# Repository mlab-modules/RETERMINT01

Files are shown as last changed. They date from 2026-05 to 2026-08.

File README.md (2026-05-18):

# RETERMINT01 – RETERMINAL DM Interface Board

<div align="center">
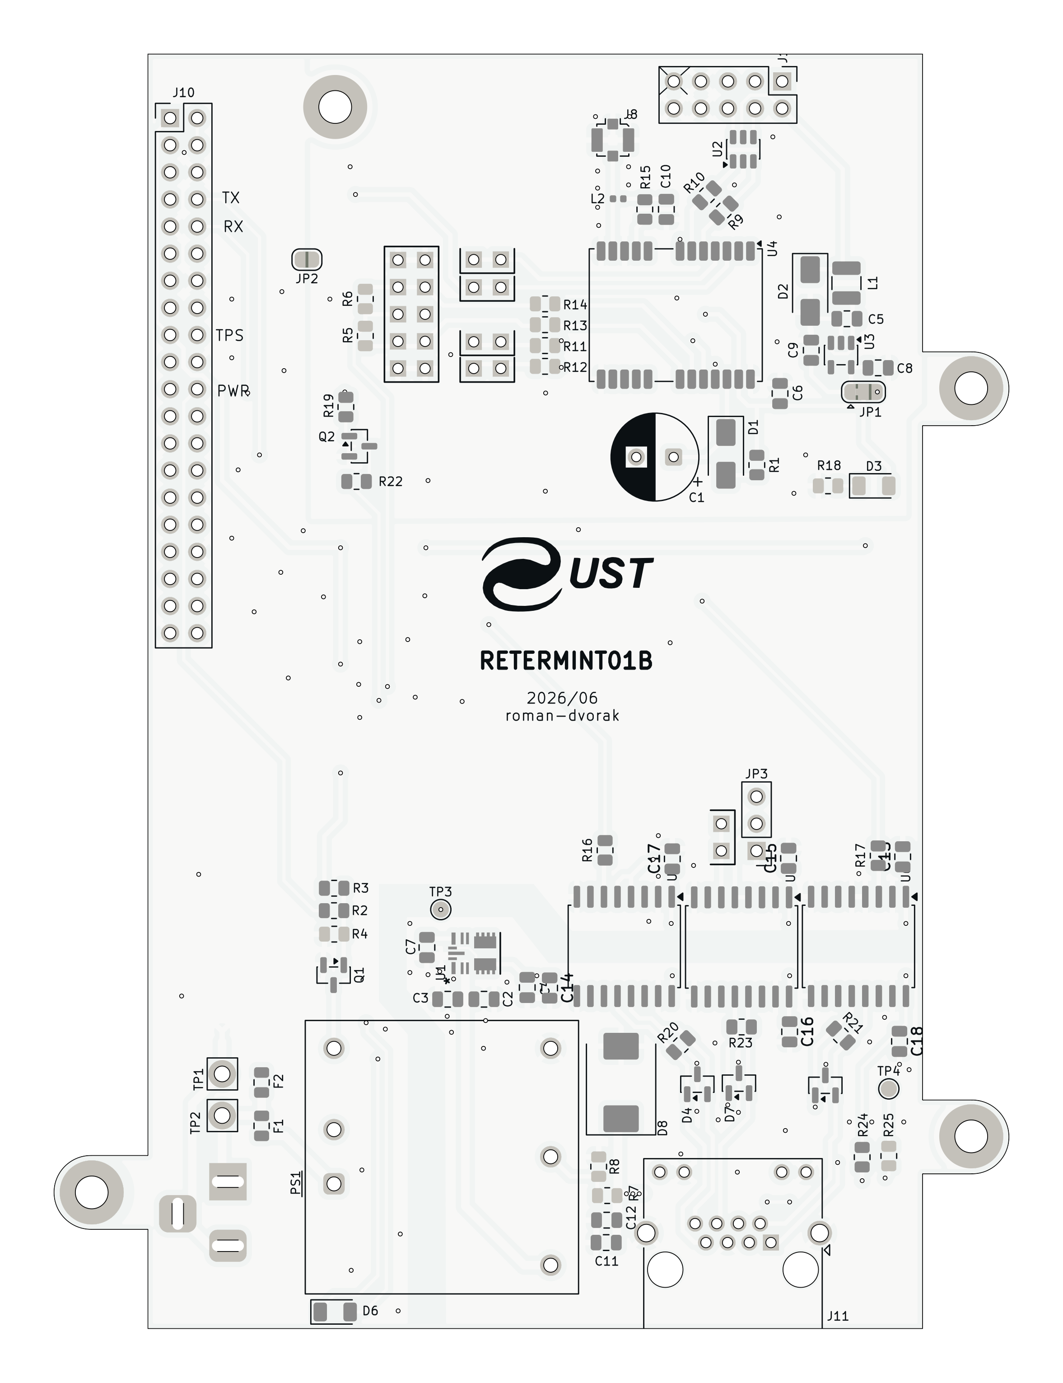
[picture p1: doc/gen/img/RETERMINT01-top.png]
Top side
  
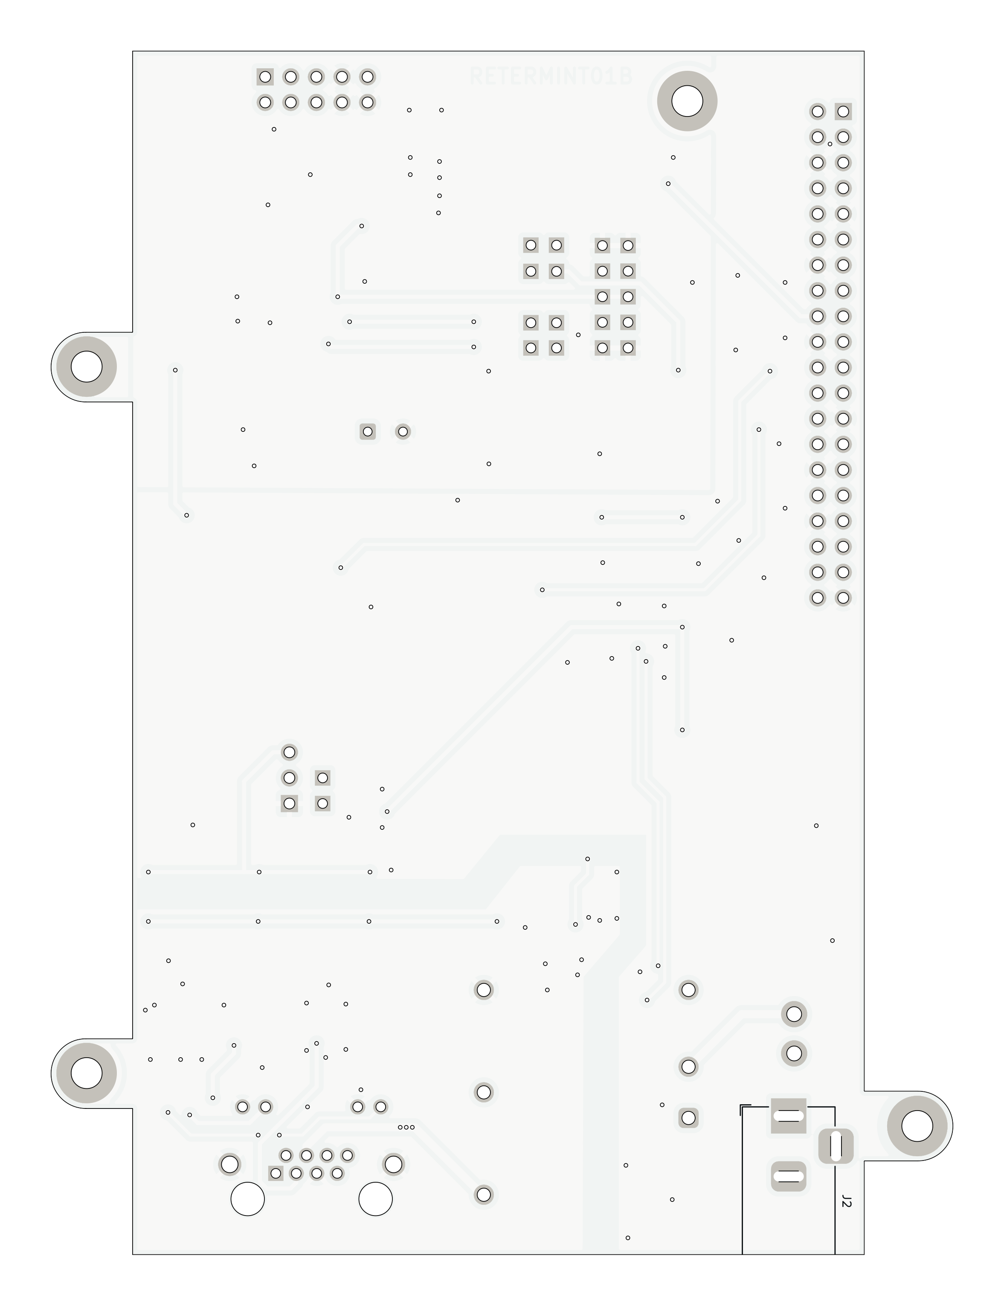
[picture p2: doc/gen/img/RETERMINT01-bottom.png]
Bottom side
  
</div>

RETERMINT01 is an interface board for the [reTerminal DM](https://wiki.seeedstudio.com/reterminal-dm/) by Seeed Studio. It adds a galvanically isolated industrial interface — **3× RS-485** bus, **isolated 24 V power supply** and the ability to **remotely switch off the power** of a connected field device via GPIO. All communication on the bus side is fully galvanically isolated from the reTerminal DM logic.

The board connects directly to the 40-pin GPIO header of the reTerminal DM.

## Features

- **3× RS-485** – galvanically isolated half-duplex channels (ADM2483xRW), up to 500 kbps
- **Isolated 24 V DC/DC** – 30 W Traco Power THN 30-2423WI, software-controllable (default OFF)
- **Remote power switching** – PS1 output controlled via `PWR_OFF` GPIO signal (active LOW)
- **5 V power module** – TI TPSM33606S5, powers the isolated RS-485 bus side
- **u-blox NEO-M9N GPS** – with u.FL antenna connector, USB configuration port and 1 F supercapacitor backup
- **Shielded RJ45 with LEDs** – for RS-485 field bus connection
- **ESD & overvoltage protection** – SM712 TVS on every RS-485 channel, USBLC6-2SC6 on GPS USB
- **2× 1 A fuse** – on 24 V input paths

## Schematic

Schematic

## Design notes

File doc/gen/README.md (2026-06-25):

# PCB

Board size: 89.6x119.5 mm (3.53x4.7 inches)

- This is the size of the rectangle that contains the board
- Thickness: 1.6 mm (63 mils)
- Material: FR4
- Finish: HAL
- Layers: 2
- Copper thickness: 35 µm

Solder mask: TOP / BOTTOM

- Color: Green

Silk screen: TOP / BOTTOM

- Color: White

# Important sizes

Clearance: 0.2 mm (8 mils)

Track width: 0.2 mm (8 mils)

- By design rules: 0.0 mm (0 mils)

Drill: 0.4 mm (16 mils)

- Vias: 0.4 mm (16 mils) [Design: 0.4 mm (16 mils)]
- Pads: 0.9 mm (35 mils)
- The above values are real drill sizes, they add 0.1 mm (4 mils) to plated holes (PTH)

Via: 0.6/0.3 mm (24/12 mils)

- By design rules: 0.5/0.3 mm (20/12 mils)
- Micro via: yes [0.2/0.1 mm (8/4 mils)]
- Buried/blind via: yes
- Total: 124 (thru: 124 buried/blind: 0 micro: 0)

Outer Annular Ring: 0.1 mm (4 mils)

- By design rules: 0.2 mm (8 mils)

Eurocircuits class: 6C
- Using min drill 0.35 mm for an OAR of 0.13 mm

# General stats

Components count: (SMD/THT)

- Top: 64/23 (SMD + THT)
- Bottom: 0/2 (THT)

Defined tracks:

- 0.2 mm (8 mils)
- 0.3 mm (12 mils)
- 0.4 mm (16 mils)
- 0.8 mm (31 mils)
- 1.0 mm (39 mils)

Used tracks:

- 0.2 mm (8 mils) (6) defined: yes
- 0.3 mm (12 mils) (113) defined: yes
- 0.4 mm (16 mils) (247) defined: yes
- 0.7 mm (28 mils) (1) defined: no
- 0.8 mm (31 mils) (37) defined: yes

Defined vias:

Used vias:

- 0.6/0.3 mm (24/12 mils) (Count: 124, Aspect: 2.7 A) defined: no

Holes (excluding vias):

- 0.8 mm (31 mils) (2)
- 0.89 mm (35 mils) (20)
- 0.89 mm (35 mils) (12)
- 1.0 mm (39 mils) (53)
- 1.24 mm (49 mils) (6)
- 1.4 mm (55 mils) (2)
- 1.57 mm (62 mils) (2)
- 3.0 mm (118 mils) (4)
- 3.25 mm (128 mils) (2)

Oval holes:

- 1.0x3.0 mm (39x118 mils) (3)

Drill tools (including vias and computing adjusts and rounding):

- 0.4 mm (16 mils) (124)
- 0.9 mm (35 mils) (2)
- 1.0 mm (39 mils) (32)
- 1.1 mm (43 mils) (56)
- 1.35 mm (53 mils) (6)
- 1.5 mm (59 mils) (2)
- 1.65 mm (65 mils) (2)
- 3.1 mm (122 mils) (4)
- 3.25 mm (128 mils) (2)

Solder paste stats:

Using a paste with 87.75 % alloy, that has an specific gravity for the alloy of 7.4 g/cm³
and 1.0 g/cm³ for the flux. This paste has an specific gravity of  4.15 g/cm³.

The stencil thickness is  0.12 mm.

| Side | Pads with paste | Area [mm²] | Paste [g] |
|---|---|---|---|
| Total  | 215 | 299.03 | 1.49 |

Note: this is just an approximation to the theoretical value. Margins of the solder mask and waste aren't computed.

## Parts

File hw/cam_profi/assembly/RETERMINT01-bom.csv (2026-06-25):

Component | Description | Part | References | Value | Footprint | Quantity Per PCB | Datasheet | ust_id | height | mouser part number | mouser price/stock | manufacturer_name | manufacturer_part_number
1 |  | C-Device | C10 | 47pF | C_0805_2012Metric | 1 |  | 5c70984712875079b91f8b38
2 | Unpolarized capacitor, small symbol | C_Small | C3C12C13C14C15C16C17C18 | 100nF | C_0805_2012Metric | 8 |  | 5c70984712875079b91f8b4c
3 |  | C-Device | C9 | 100nF | C_0805_2012Metric | 1 |  | 5c70984712875079b91f8b4c
4 | Unpolarized capacitor, small symbol | C_Small | C2C4C11 | 1uF | C_0805_2012Metric | 3 |  | 5c70984712875079b91f8b50
5 |  | C-Device | C6C7C8 | 1uF | C_0805_2012Metric | 3 |  | 5c70984712875079b91f8b50
6 |  | C-Device | C5 | 10uF | C_0805_2012Metric | 1 |  | 5c70984812875079b91f8bbe
7 |  | CP-Device | C1 | 1F | CP_Radial_D8.0mm_P3.50mm | 1 |  | 5c70984412875079b91f8873
8 |  | LED-Device | D6 | GREEN | LED_1206_3216Metric | 1 |  | 5c70984412875079b91f8895
9 |  | D-Device | D1D2 | M4 | D_SMA | 2 |  | 5c70984512875079b91f88ac
10 | 7V/12V, 600W Asymmetrical TVS Diode Array, SOT-23 | SM712_SOT23 | D4D5D7 | SM712_SOT23 | SOT-23 | 3 | https://www.littelfuse.com/~/media/electronics/datasheets/tvs_diode_arrays/littelfuse_tvs_diode_array_sm712_datasheet.pdf.pdf | ?
11 | Schottky diode, small symbol | D_Schottky_Small | D8 | SMCJ33A | D_SMC | 1
12 | Fuse, small symbol | Fuse_Small | F1F2 | 1A | Fuse_0805_2012Metric | 2
13 | Generic connector, double row, 02x05, odd/even pin numbering scheme (row 1 odd numbers, row 2 even numbers), script generated (kicad-library-utils/schlib/autogen/connector/) | Conn_02x05_Odd_Even | J1 | Conn_02x05_Odd_Even | PinHeader_2x05_P2.54mm_Vertical | 1
14 | 2x01 2.54 mm pitch header, 2 pins next to each other are connected | HEADER_2x01_PARALLEL | J9 | HEADER_2x01_PARALLEL | Straight_2x01 | 1
15 | RJ connector, 8P8C (8 positions 8 connected), two LEDs, Shielded | RJ45_LED_Shielded | J11 | RJ45_LED_Shielded | RJ45_Amphenol_RJHSE538X | 1
16 | Raspberry Pi 4 Model B | Raspberry_Pi_4 | J10 | Raspberry_Pi_4 | PinHeader_2x20_P2.54mm_Vertical | 1 | https://datasheets.raspberrypi.com/rpi4/raspberry-pi-4-datasheet.pdf
17 | small coaxial connector (BNC, SMA, SMB, SMC, Cinch/RCA, LEMO, ...) | Conn_Coaxial_Small | J8 | u.fl | U.FL_Molex_MCRF_73412-0110_Vertical | 1 |  | 5ed7ac8e12875004e15a62c8
18 |  | L-Device | L2 | 27nH | L_0402_1005Metric | 1 | LQG15HS27NJ02D | 618cbf071287506e2801ed7e
19 |  | L-Device | L1 | NL322522T-101K | L_1210_3225Metric | 1 |  | 5c70984412875079b91f87fb
20 | 30 Watt DC/DC converter, industrial, 4:1 input, encpasulated, 1.0" x 1.0" metal package | THN_30-2423WI | PS1 | THN-30-2415WIR | Converter_DCDC_TRACO_THN30-xxxx_THT | 1 | https://tracopower.com/thn30wi-datasheet/ |  | 10.4 | 495-THN30-2415WIR | https://www.mouser.co.uk/ProductDetail/TRACO-Power/THN-30-2423WI?qs=ckJk83FOD0VxUQUqsS4xBQ%3D%3D | Traco Power | THN-30-2415WIR
21 | NPN transistor, base/emitter/collector | Q_NPN_BEC | Q1Q2 | BC817-25 | SOT-23 | 2 |  | 5c70984712875079b91f8aea
22 |  | R-Device | R15 | 10R | R_0805_2012Metric | 1 |  | 5c70984512875079b91f896d
23 |  | R-Device | R1 | 22R | R_0805_2012Metric | 1 |  | 5c70984512875079b91f896f
24 |  | R-Device | R9R10R16R17 | 33R | R_0805_2012Metric | 4 |  | 5c70984512875079b91f8970
25 | Resistor | R | R19R20R21R22R23R24 | 220R | R_0805_2012Metric | 6 |  | 5c70984512875079b91f897f
26 | Resistor | R | R2 | 1k | R_0805_2012Metric | 1 |  | 5c70984512875079b91f898c
27 |  | R-Device | R3 | 10k | R_0805_2012Metric | 1 |  | 5c70984612875079b91f899f
28 | Isolated RS485/RS422 Transceiver, Half-Duplex, 500kbps, SOIC-16W | ADM2483xRW | U5U6U7 | ADM2483xRW | SOIC-16W_7.5x10.3mm_P1.27mm | 3 | https://www.analog.com/media/en/technical-documentation/data-sheets/adm2483.pdf
29 |  | MIC5504-3.3YM5-Regulator_Linear | U3 | MIC5504-3.3YM5 | SOT-23-5 | 1 | http://ww1.microchip.com/downloads/en/DeviceDoc/MIC550X.pdf | 5c7255e81287500b4e112ea2
30 |  | NEO-M8P-RF_GPS | U4 | NEO-M9N | ublox_NEO | 1 | https://www.u-blox.com/sites/default/files/NEO-M8P_DataSheet_%28UBX-15016656%29.pdf | 5fa0faaf12875025b3977985
31 |  | TPSM33606S5QRDNRQ1 | U1 | TPSM33606S5QRDNRQ1 | RDN0011A_TEX | 1 | https://www.ti.com/lit/gpn/tpsm33606-q1
32 |  | USBLC6-2SC6-Power_Protection | U2 | USBLC6-2SC6 | SOT-23-6 | 1 | http://www2.st.com/resource/en/datasheet/CD00050750.pdf | 5e82e0691287502a334a778c

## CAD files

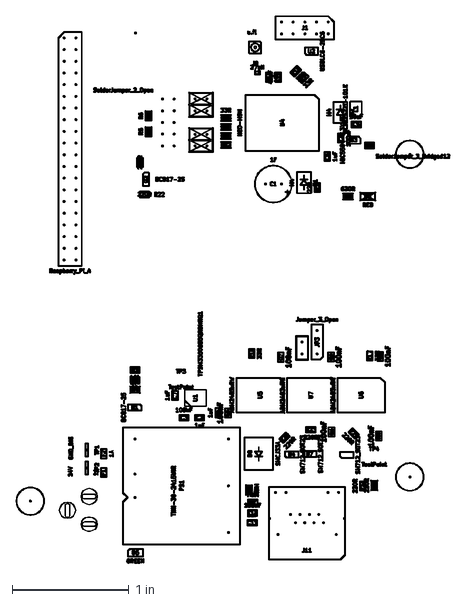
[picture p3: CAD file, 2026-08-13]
doc/gen/dxf/RETERMINT01-F_Fab.dxf
3.71 x 4.68 in

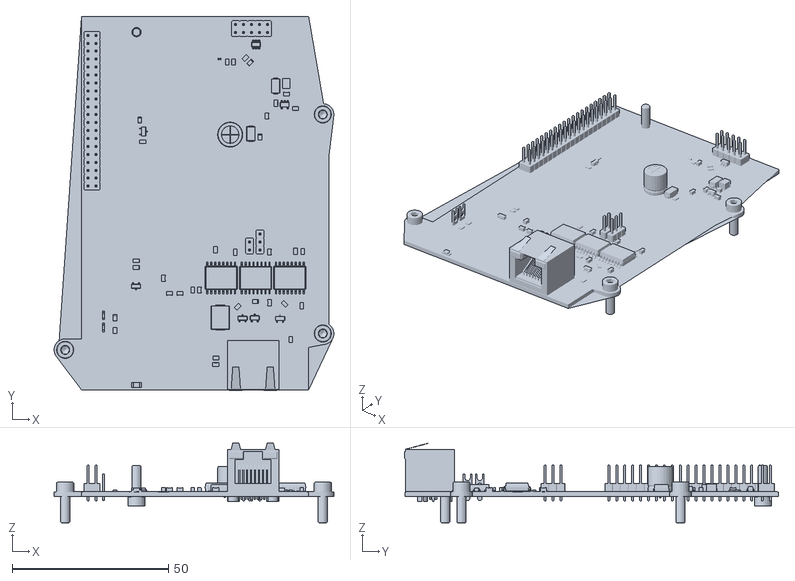
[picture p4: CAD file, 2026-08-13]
doc/gen/mesh/RETERMINT01.stl
89.6 x 119.7 x 25.5

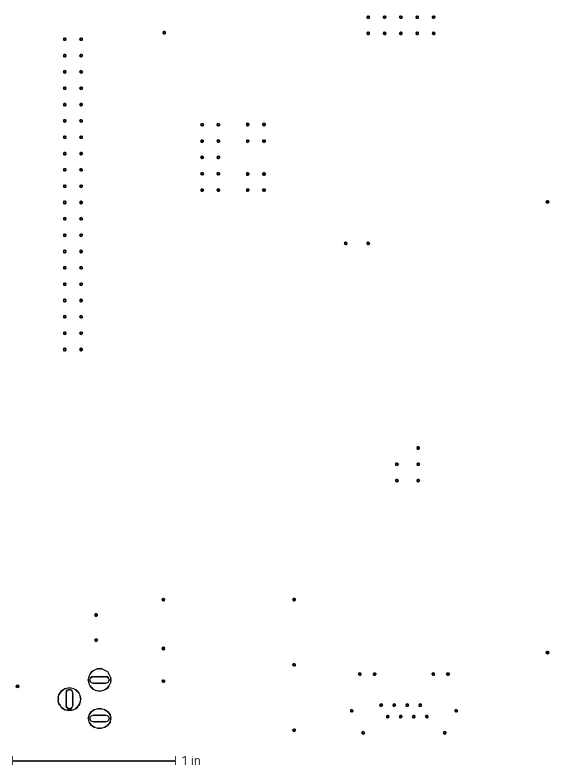
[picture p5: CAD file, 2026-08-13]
doc/gen/dxf/RETERMINT01-User_3.dxf
3.26 x 4.40 in

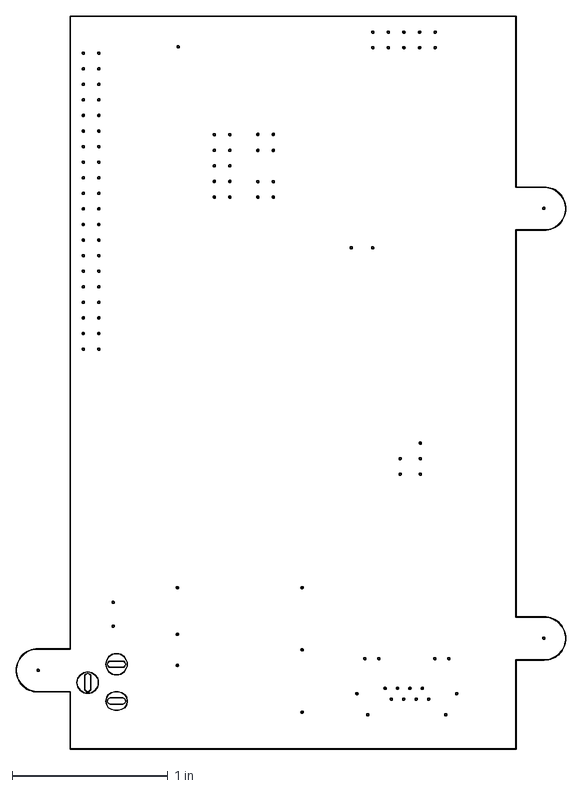
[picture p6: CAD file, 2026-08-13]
doc/gen/dxf/RETERMINT01-Edge_Cuts.dxf
3.53 x 4.71 in

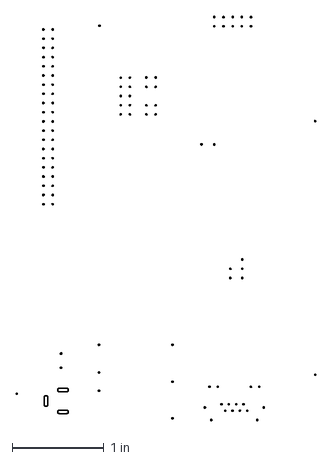
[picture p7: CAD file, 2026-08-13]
doc/gen/dxf/RETERMINT01-F_Adhesive.dxf
3.26 x 4.40 in

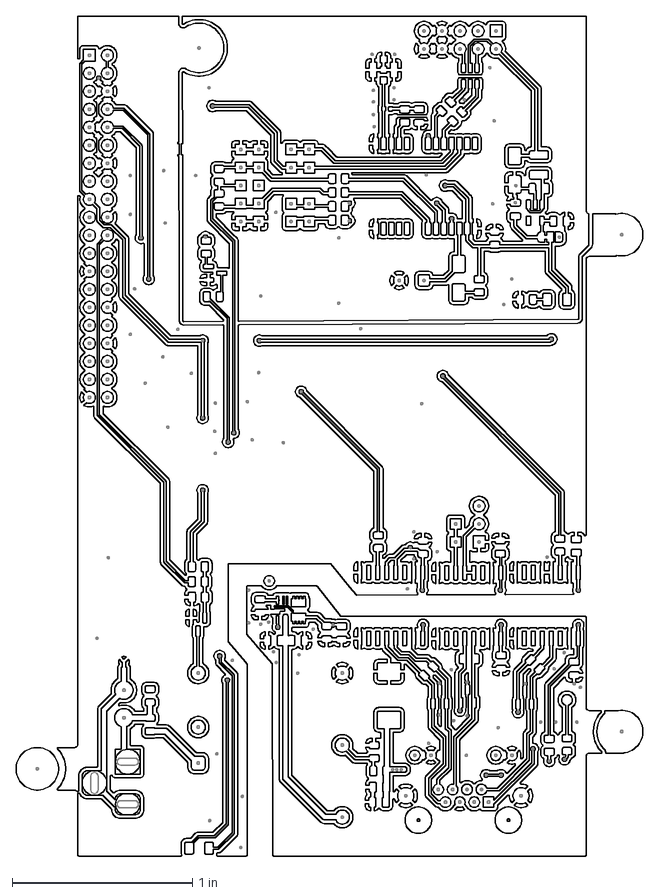
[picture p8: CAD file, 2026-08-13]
doc/gen/dxf/RETERMINT01-F_Cu.dxf
3.48 x 4.67 in

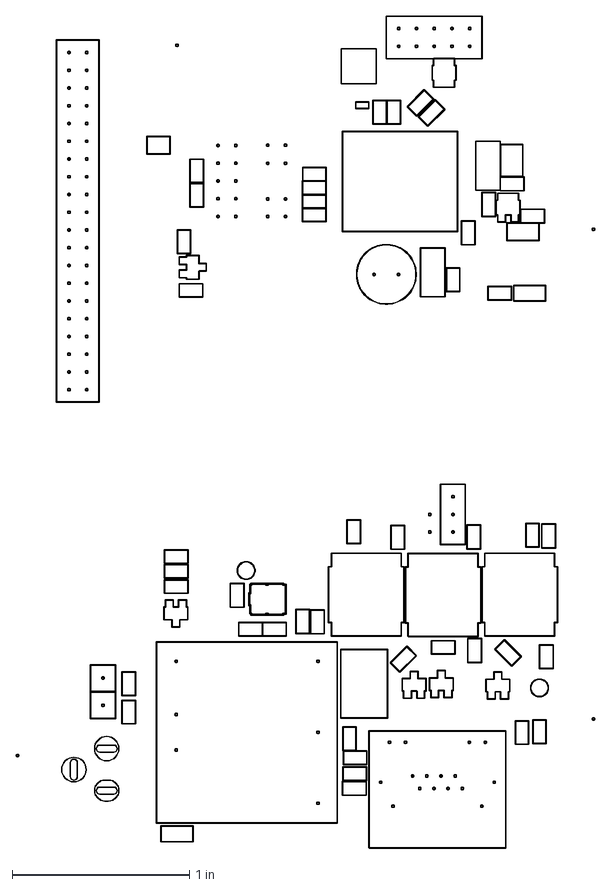
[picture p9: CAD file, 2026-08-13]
doc/gen/dxf/RETERMINT01-F_Courtyard.dxf
3.26 x 4.69 in

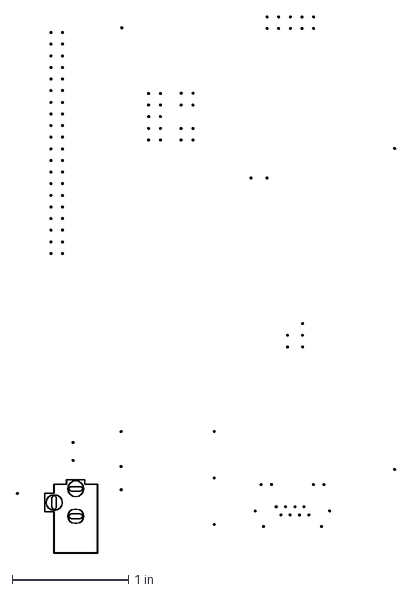
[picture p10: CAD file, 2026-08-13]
doc/gen/dxf/RETERMINT01-B_Courtyard.dxf
3.26 x 4.62 in

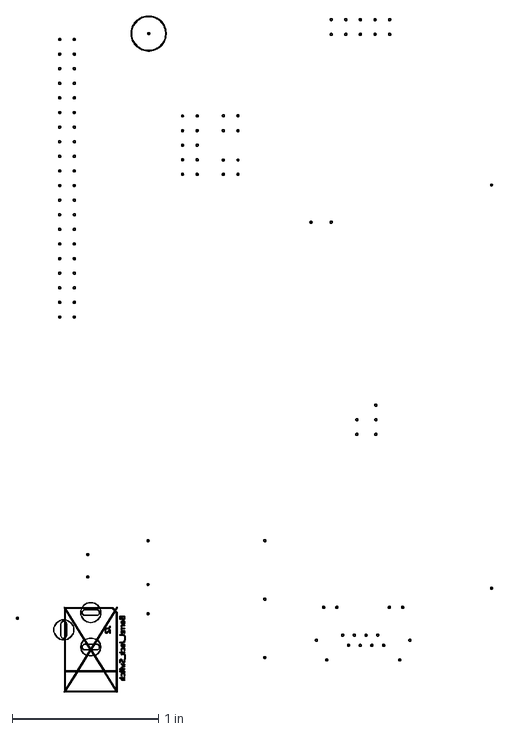
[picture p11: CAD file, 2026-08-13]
doc/gen/dxf/RETERMINT01-B_Fab.dxf
3.26 x 4.63 in

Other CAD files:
doc/gen/dxf/RETERMINT01-B_Cu.dxf
doc/gen/dxf/RETERMINT01-B_Mask.dxf
doc/gen/dxf/RETERMINT01-B_Silkscreen.dxf
doc/gen/dxf/RETERMINT01-F_Mask.dxf
doc/gen/dxf/RETERMINT01-F_Paste.dxf
doc/gen/dxf/RETERMINT01-F_Silkscreen.dxf

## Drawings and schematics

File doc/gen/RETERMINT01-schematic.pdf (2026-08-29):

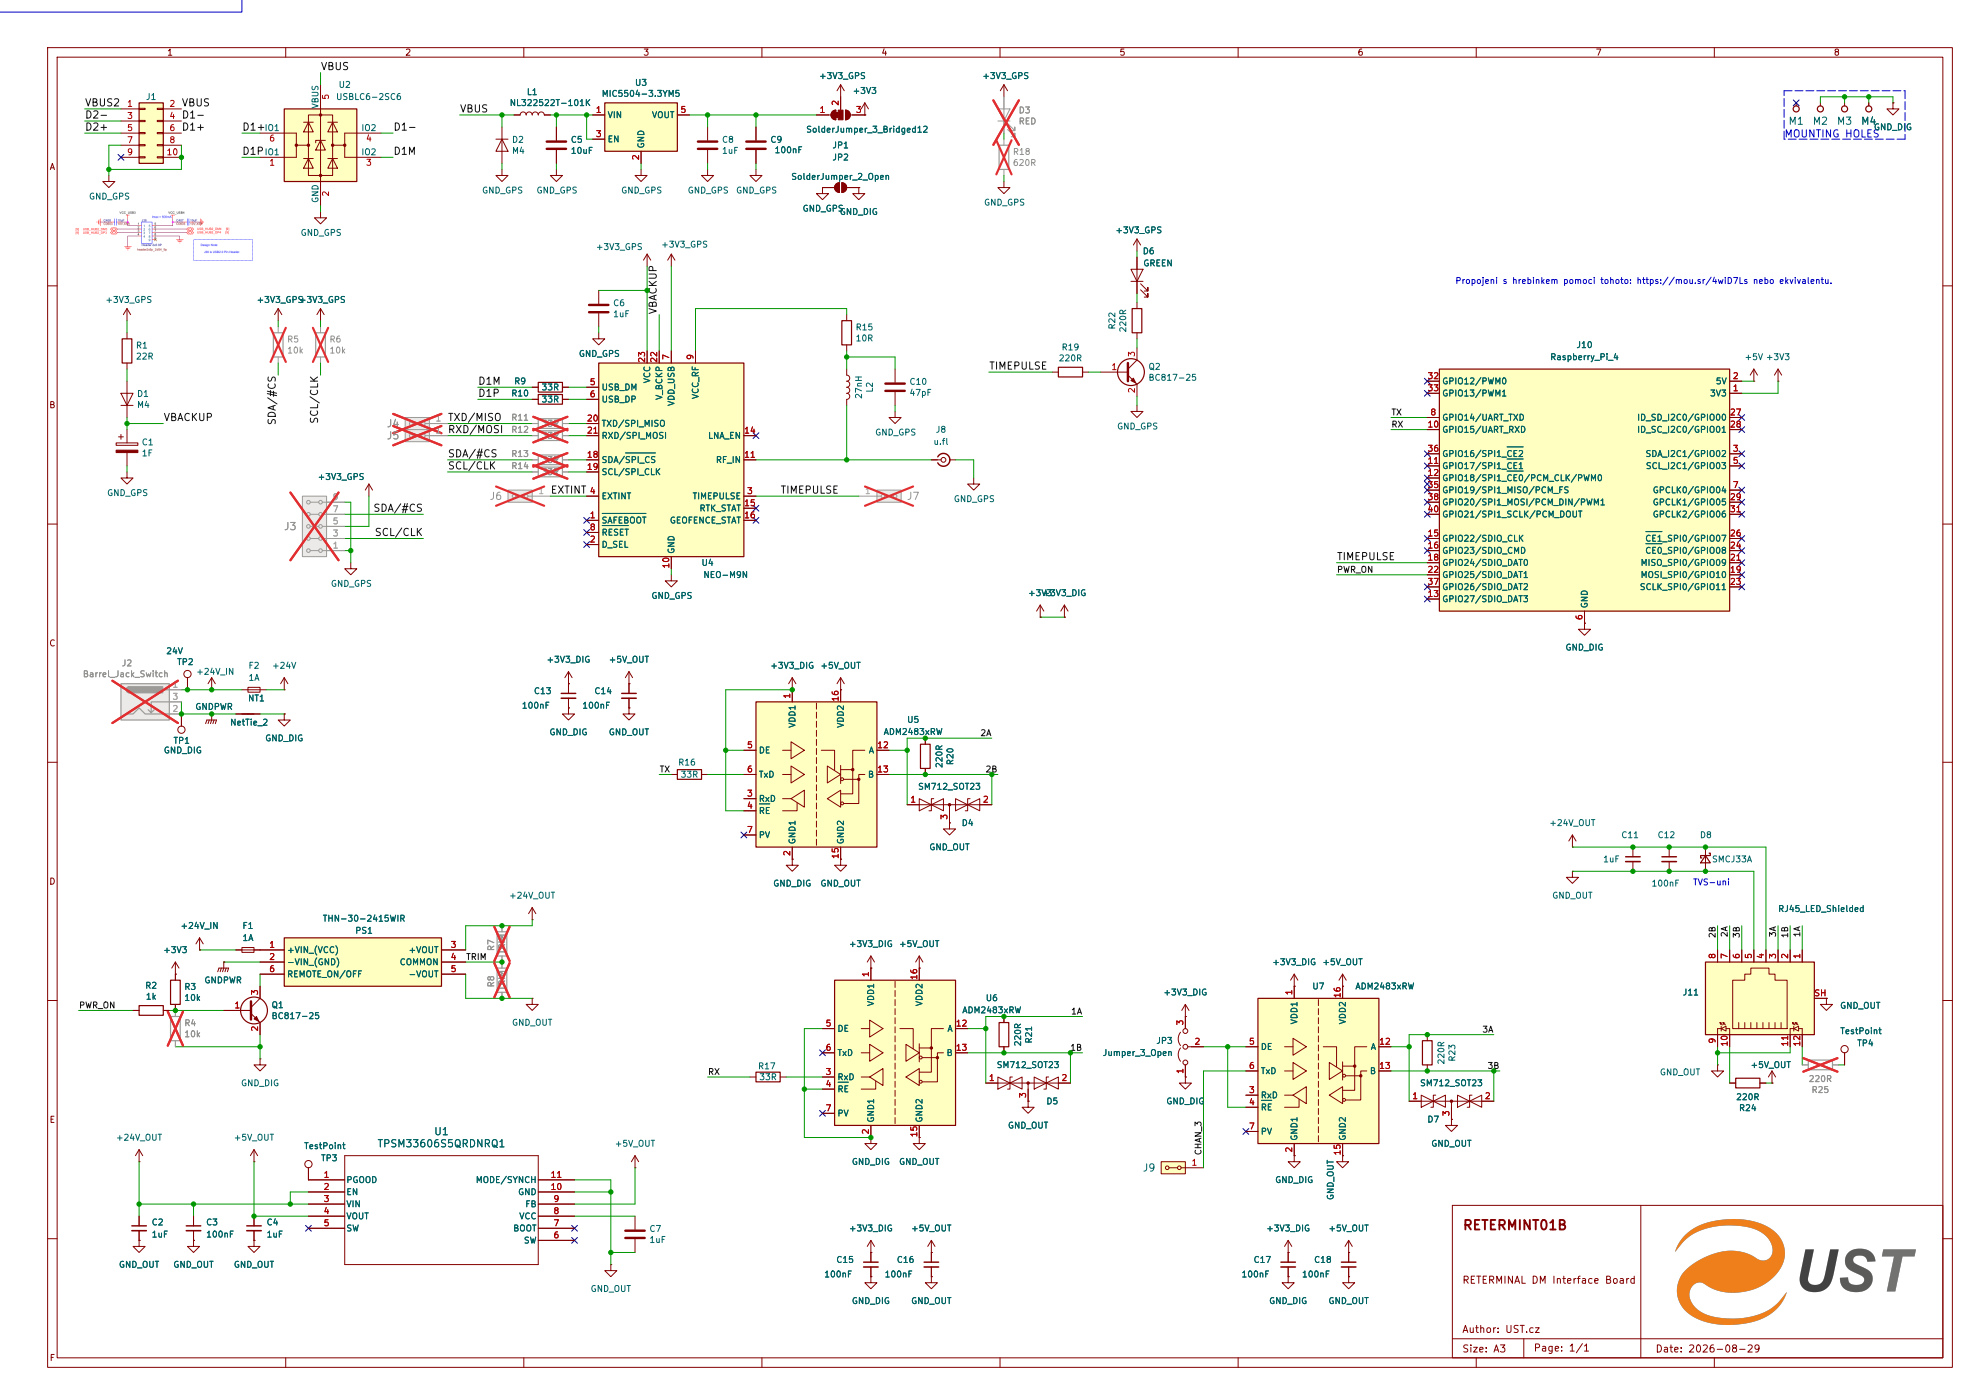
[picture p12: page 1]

Propojeni s hrebinkem pomoci tohoto: https://mou.sr/4wiD7Ls nebo ekvivalentu.

RETERMINAL DM Interface Board +5V_OUT

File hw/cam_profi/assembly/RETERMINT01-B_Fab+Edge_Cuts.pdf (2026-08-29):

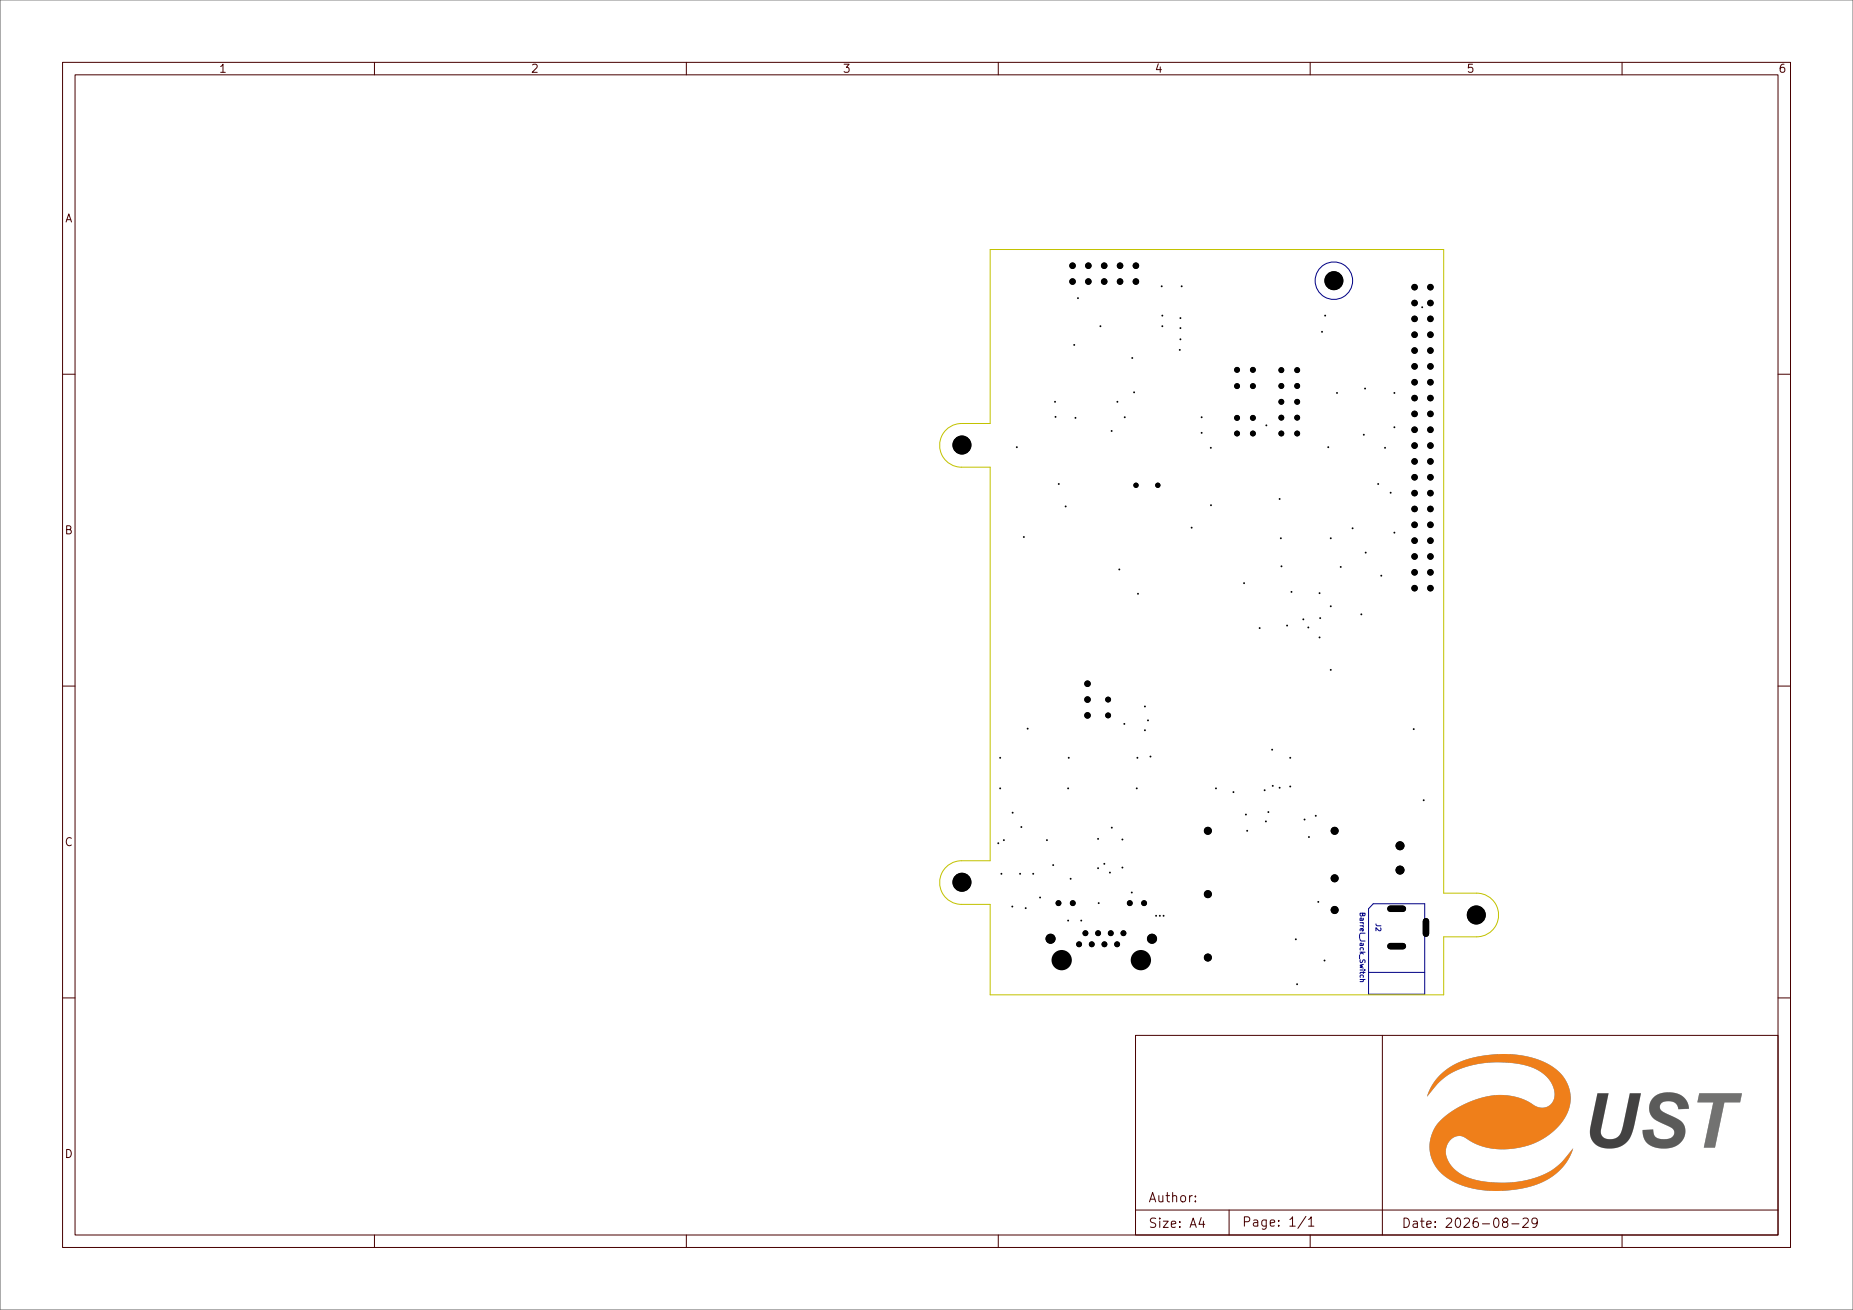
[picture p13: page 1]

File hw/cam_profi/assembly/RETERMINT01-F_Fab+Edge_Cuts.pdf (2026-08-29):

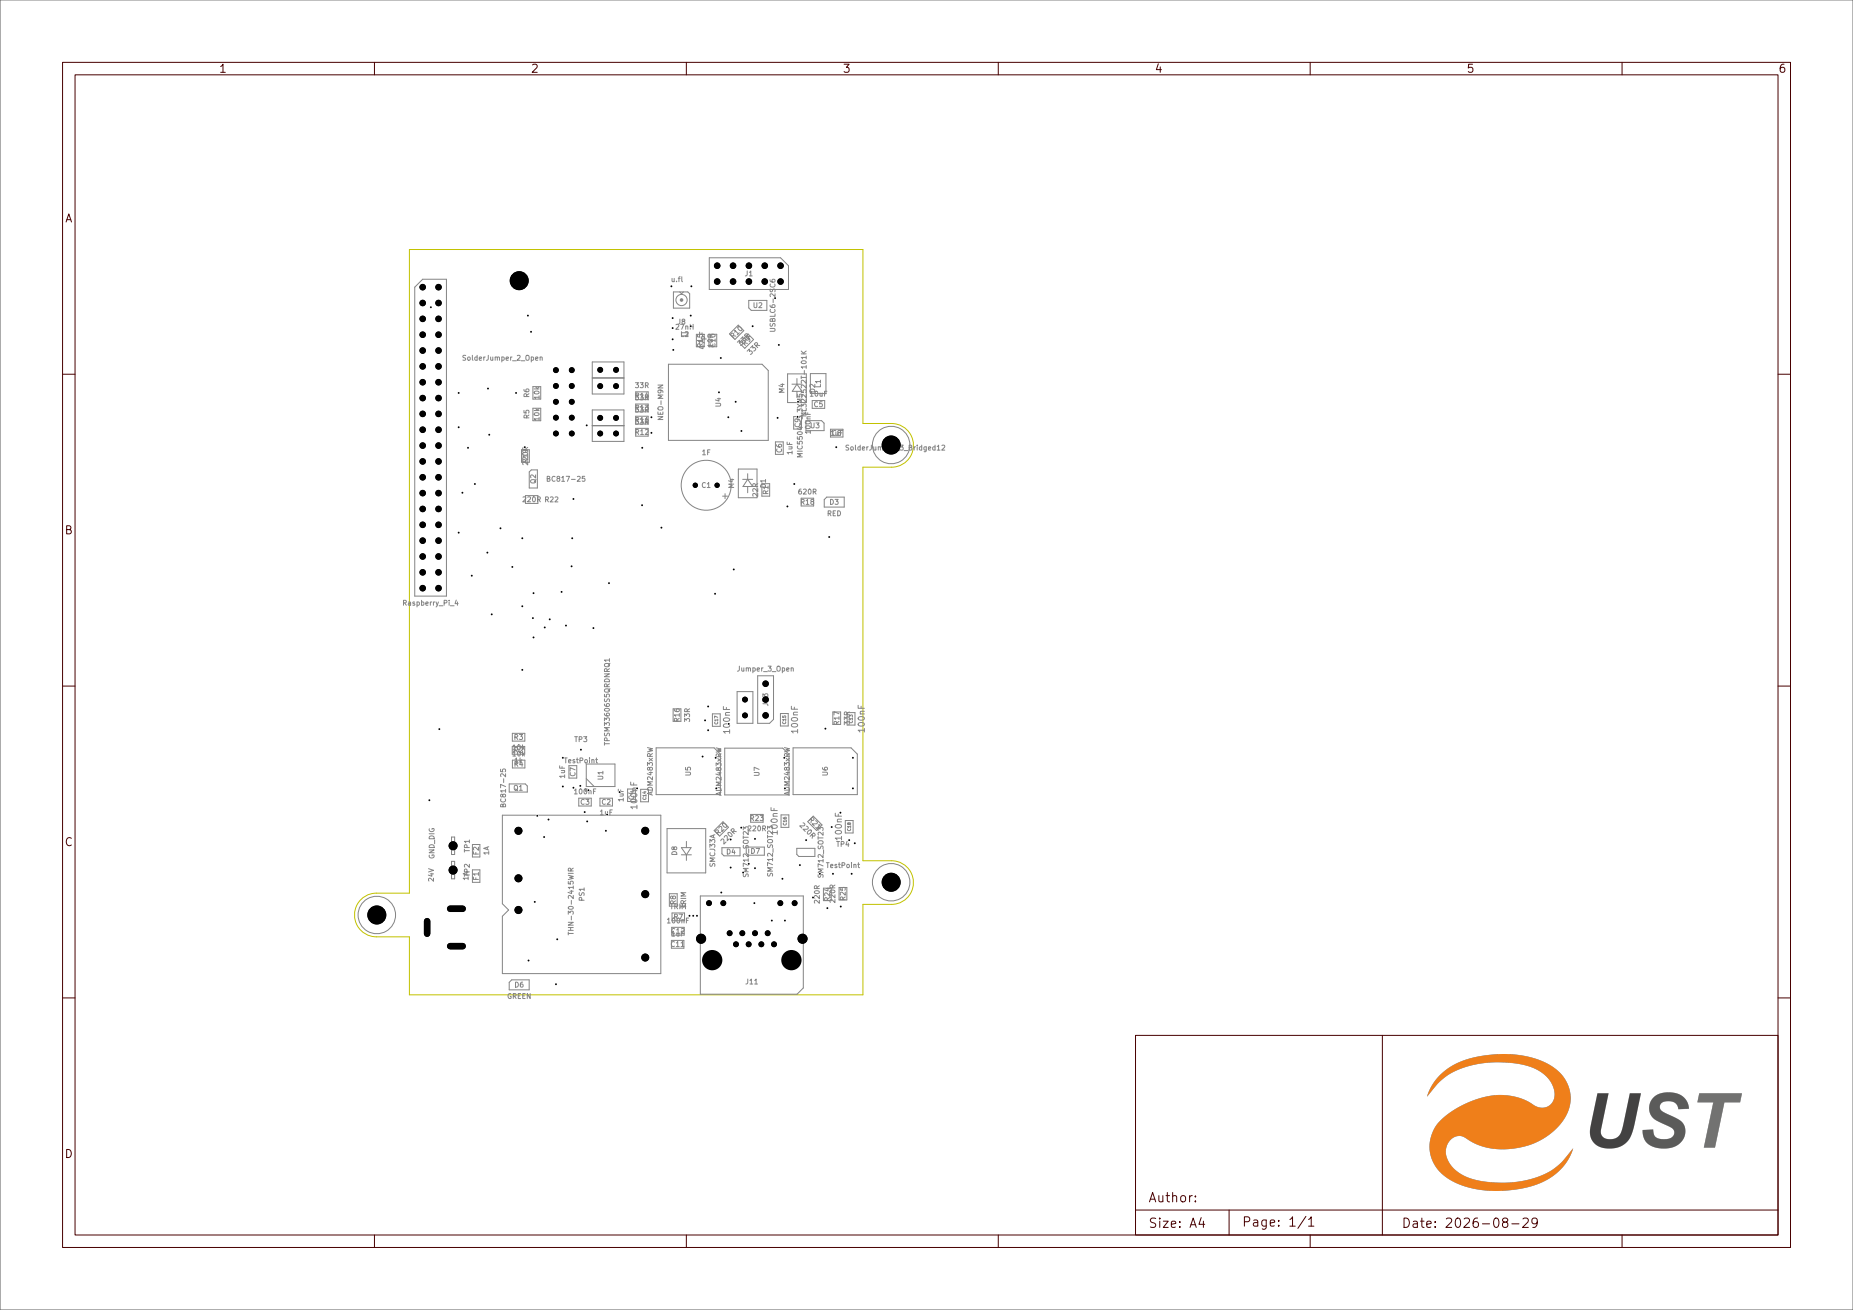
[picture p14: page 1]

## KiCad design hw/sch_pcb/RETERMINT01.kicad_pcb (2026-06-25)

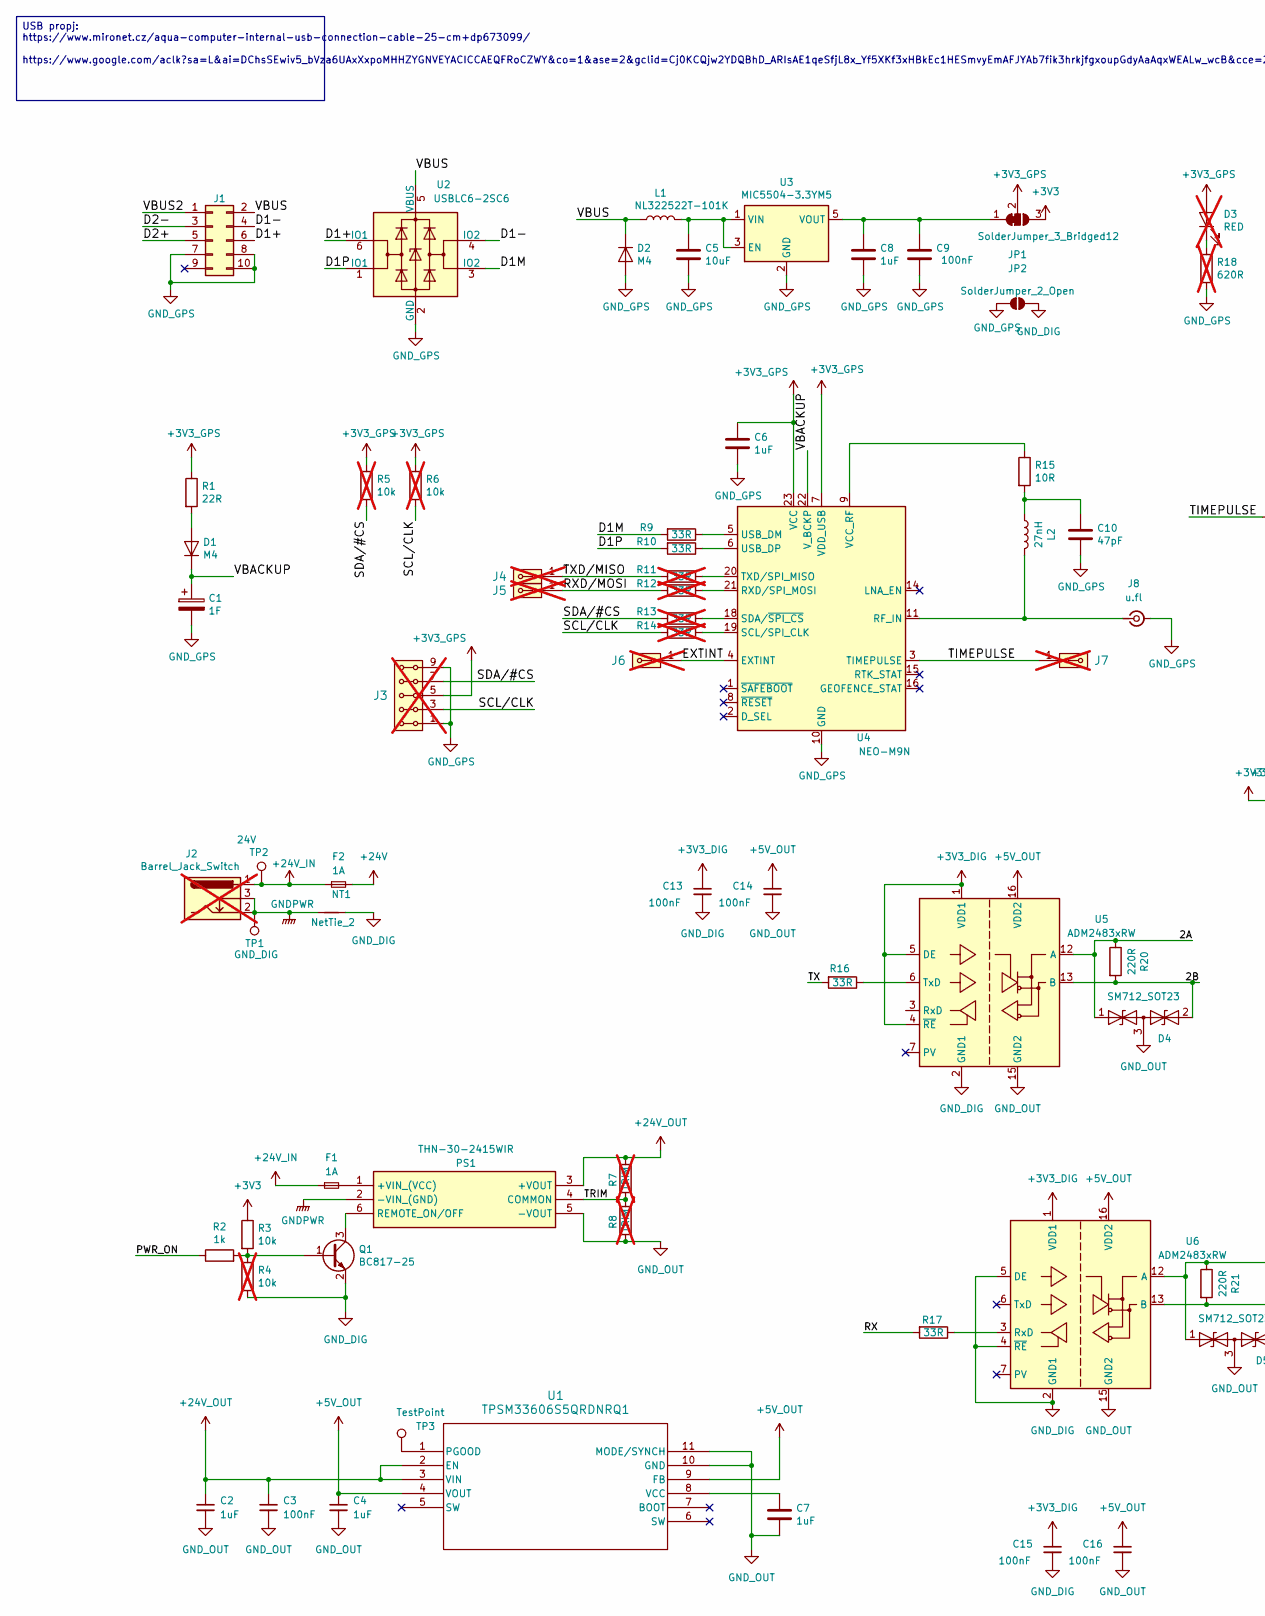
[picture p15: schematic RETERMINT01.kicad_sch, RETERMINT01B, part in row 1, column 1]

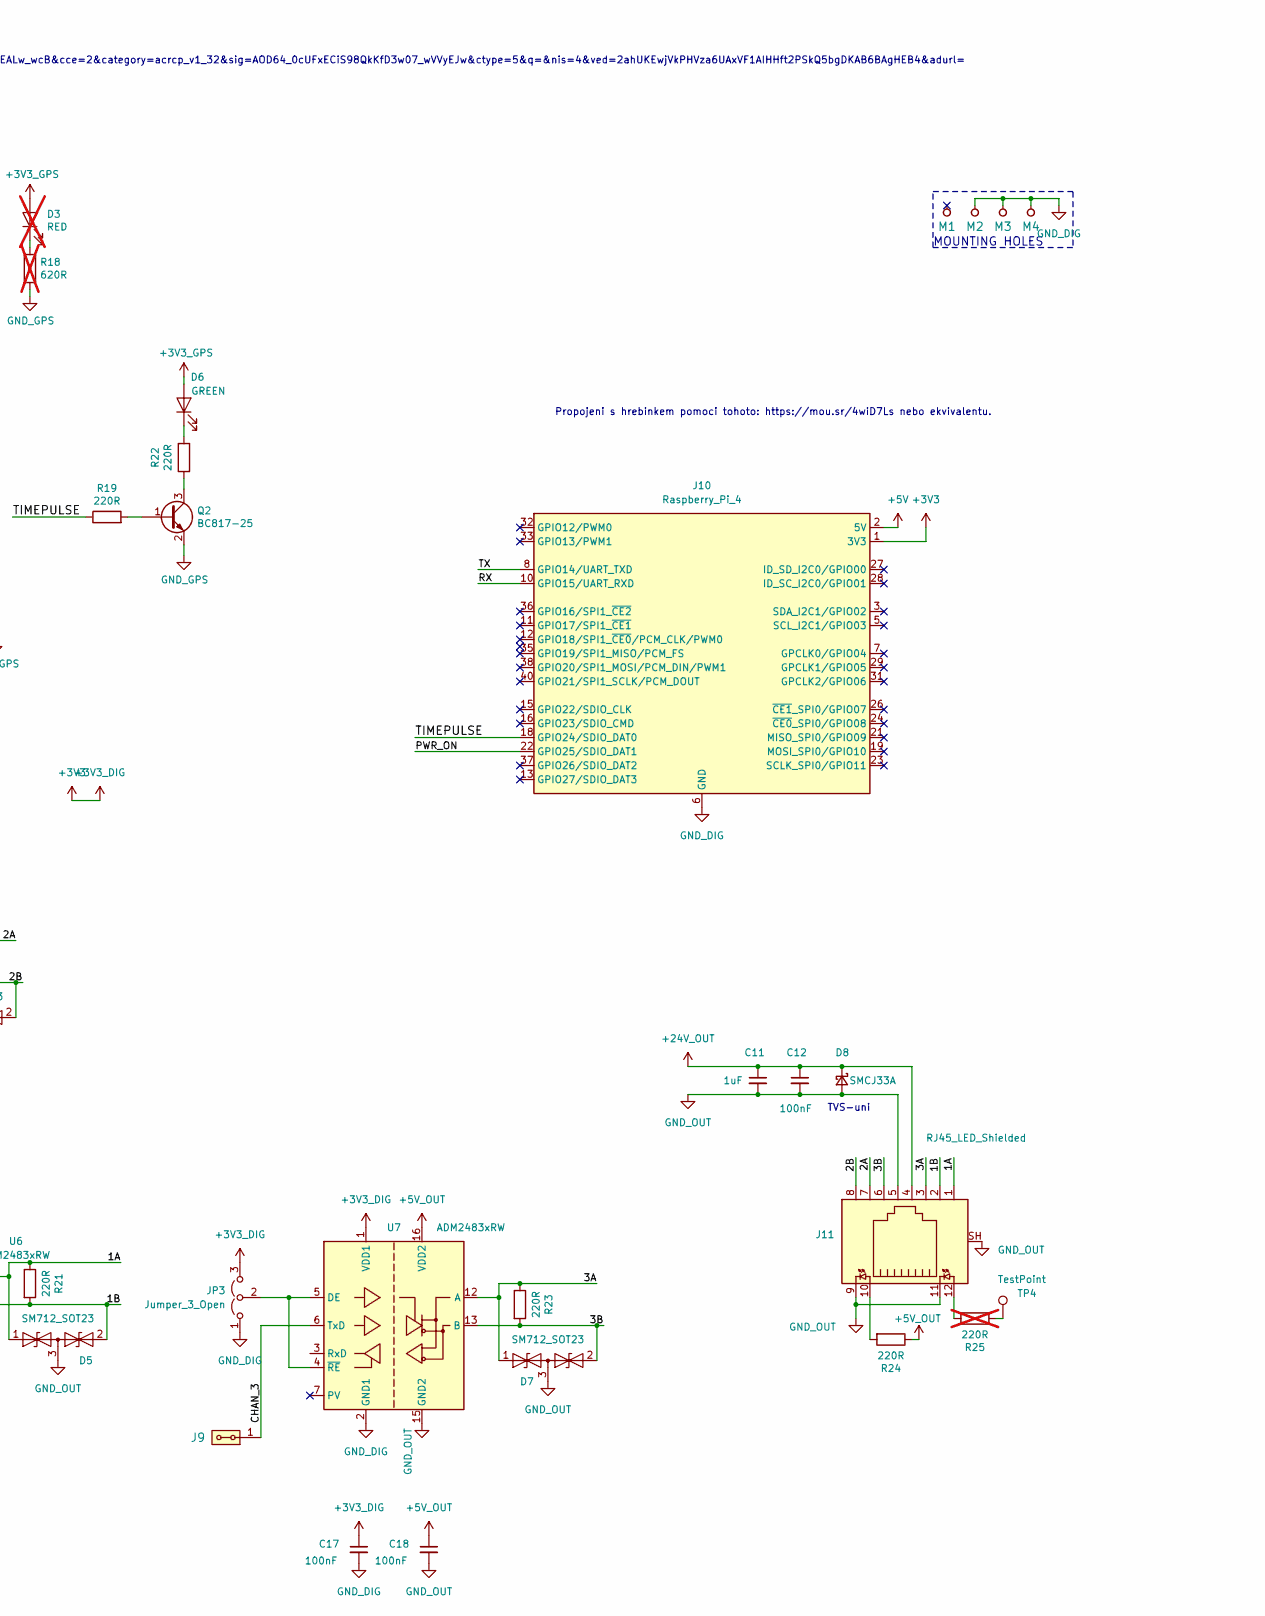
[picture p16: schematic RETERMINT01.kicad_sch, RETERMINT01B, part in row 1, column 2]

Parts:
C1: 1F; CP_Radial_D8.0mm_P3.50mm
C2, C4, C6, C7, C8, C11: 1uF; C_0805_2012Metric
C3, C9, C12, C13, C14, C15, C16, C17, C18: 100nF; C_0805_2012Metric
C5: 10uF; C_0805_2012Metric
C10: 47pF; C_0805_2012Metric
D1, D2: M4; D_SMA
D3: RED; LED_1206_3216Metric; not fitted
D4, D5, D7: SM712_SOT23; SOT-23
D6: GREEN; LED_1206_3216Metric
D8: SMCJ33A; D_SMC
F1, F2: 1A; Fuse_0805_2012Metric
J1: Conn_02x05_Odd_Even; PinHeader_2x05_P2.54mm_Vertical
J2: Barrel_Jack_Switch; BarrelJack_Horizontal; not fitted
J3: HEADER_2x05_PARALLEL; Straight_2x05; not fitted
J4, J5, J6, J7: HEADER_2x01_PARALLEL; Straight_2x01; not fitted
J8: u.fl; U.FL_Molex_MCRF_73412-0110_Vertical
J9: HEADER_2x01_PARALLEL; Straight_2x01
J10: Raspberry_Pi_4; PinHeader_2x20_P2.54mm_Vertical
J11: RJ45_LED_Shielded; RJ45_Amphenol_RJHSE538X
JP1: SolderJumper_3_Bridged12; SolderJumper-3_P1.3mm_Bridged12_RoundedPad1.0x1.5mm
JP2: SolderJumper_2_Open; SolderJumper-2_P1.3mm_Open_RoundedPad1.0x1.5mm
JP3: Jumper_3_Open; PinHeader_1x03_P2.54mm_Vertical
L1: NL322522T-101K; L_1210_3225Metric
L2: 27nH; L_0402_1005Metric
M1, M2, M3, M4: HOLE; MountingHole_3mm
NT1: NetTie_2; NetTie-2_SMD_Pad0.5mm
PS1: THN-30-2415WIR; Converter_DCDC_TRACO_THN30-xxxx_THT; Mouser Part Number 495-THN30-2415WIR
Q1, Q2: BC817-25; SOT-23
R1: 22R; R_0805_2012Metric
R2: 1k; R_0805_2012Metric
R3: 10k; R_0805_2012Metric
R4, R5, R6: 10k; R_0805_2012Metric; not fitted
R7, R8: TRIM; R_0805_2012Metric; not fitted
R9, R10, R16, R17: 33R; R_0805_2012Metric
R11, R12, R13, R14: 33R; R_0805_2012Metric; not fitted
R15: 10R; R_0805_2012Metric
R18: 620R; R_0805_2012Metric; not fitted
R19, R20, R21, R22, R23, R24: 220R; R_0805_2012Metric
R25: 220R; R_0805_2012Metric; not fitted
TP1: GND_DIG; Pin_D1.4mm_L8.5mm_W2.8mm_FlatFork
TP2: 24V; Pin_D1.4mm_L8.5mm_W2.8mm_FlatFork
TP3, TP4: TestPoint; TestPoint_Pad_D1.5mm
U1: TPSM33606S5QRDNRQ1; RDN0011A_TEX
U2: USBLC6-2SC6; SOT-23-6
U3: MIC5504-3.3YM5; SOT-23-5
U4: NEO-M9N; ublox_NEO
U5, U6, U7: ADM2483xRW; SOIC-16W_7.5x10.3mm_P1.27mm

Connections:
+3V3: C13.1, C15.1, C17.1, J10.1 (3V3), J10.17 (3V3), JP1.3 (B), JP3.3 (B), R3.1, U5.1 (VDD1), U5.4 (~RE), U5.5 (DE), U6.1 (VDD1), U7.1 (VDD1)
+3V3_GPS: C6.1, D3.2 (A), D6.2 (A), J3.5, J3.6, JP1.2 (C), R1.1, R5.1, R6.1, U4.7 (VDD_USB), U4.23 (VCC)
+5V: J10.2 (5V), J10.4 (5V)
+5V_OUT: C4.1, C14.1, C16.1, C18.1, R24.1, U1.4 (VOUT), U1.9 (FB), U5.16 (VDD2), U6.16 (VDD2), U7.16 (VDD2)
+24V: F2.2
+24V_IN: F1.1, F2.1, J2.1, TP2.1 (1_1)
+24V_OUT: C2.1, C3.1, C11.1, C12.1, D8.1 (K), J11.4, PS1.3 (+VOUT), R7.1, U1.2 (EN), U1.3 (VIN)
/1A: D5.1 (A1), J11.1, R21.1, U6.12 (A)
/1B: D5.2 (A2), J11.2, R21.2, U6.13 (B)
/2A: D4.1 (A1), J11.7, R20.1, U5.12 (A)
/2B: D4.2 (A2), J11.8, R20.2, U5.13 (B)
/3A: D7.1 (A1), J11.3, R23.1, U7.12 (A)
/3B: D7.2 (A2), J11.6, R23.2, U7.13 (B)
/CHAN_3: J9.1, J9.2, U7.6 (TxD)
/D1+: J1.6, U2.6 (IO1)
/D1-: J1.4, U2.4 (IO2)
/D1M: R9.2, U2.3 (IO2)
/D1P: R10.2, U2.1 (IO1)
/D2+: J1.5
/D2-: J1.3
/EXTINT: J6.1, J6.2, U4.4 (EXTINT)
/PWR_ON: J10.22 (GPIO25/SDIO_DAT1), R2.1
/RX: J10.10 (GPIO15/UART_RXD), R17.2
/RXD/MOSI: J5.1, J5.2, R12.2
/SCL/CLK: J3.3, J3.4, R6.2, R14.2
/SDA/#CS: J3.7, J3.8, R5.2, R13.2
/TIMEPULSE: J7.1, J7.2, J10.18 (GPIO24/SDIO_DAT0), R19.1, U4.3 (TIMEPULSE)
/TRIM: PS1.4 (COMMON), R7.2, R8.1
/TX: J10.8 (GPIO14/UART_TXD), R16.2
/TXD/MISO: J4.1, J4.2, R11.2
/VBACKUP: C1.1, D1.1 (K), U4.22 (V_BCKP)
/VBUS: D2.1 (K), J1.2, L1.1, U2.5 (VBUS)
/VBUS2: J1.1
GNDPWR: J2.2, J2.3, NT1.1, PS1.2 (-VIN_(GND)), TP1.1 (1_1)
GND_DIG: C13.2, C15.2, C17.2, J10.6 (GND), J10.9 (GND), J10.14 (GND), J10.20 (GND), J10.25 (GND), J10.30 (GND), J10.34 (GND), J10.39 (GND), JP2.2 (B), JP3.1 (A), M2.1, M3.1, M4.1, NT1.2, Q1.2 (E), R4.2, U5.2 (GND1), U5.8 (GND1), U6.2 (GND1), U6.4 (~RE), U6.5 (DE), U6.8 (GND1), U7.2 (GND1), U7.8 (GND1)
GND_GPS: C1.2, C5.2, C6.2, C8.2, C9.2, C10.2, D2.2 (A), J1.7, J1.8, J1.10, J3.1, J3.2, J3.9, J3.10, J8.2 (Ext), JP2.1 (A), Q2.2 (E), R18.2, U2.2 (GND), U3.2 (GND), U4.10 (GND), U4.12 (GND), U4.13 (GND), U4.24 (GND)
GND_OUT: C2.2, C3.2, C4.2, C7.2, C11.2, C12.2, C14.2, C16.2, C18.2, D4.3 (common), D5.3 (common), D7.3 (common), D8.2 (A), J11.5, J11.9, J11.11, J11.SH, PS1.5 (-VOUT), R8.2, U1.10 (GND), U1.11 (MODE/SYNCH), U5.9 (GND2), U5.15 (GND2), U6.9 (GND2), U6.15 (GND2), U7.9 (GND2), U7.15 (GND2)
unnamed: C10.1, L2.1, R15.2
unnamed: D1.2 (A), R1.2
unnamed: D3.1 (K), R18.1
unnamed: D6.1 (K), R22.2
unnamed: J8.1 (In), L2.2, U4.11 (RF_IN)
unnamed: J11.10, R24.2
unnamed: J11.12, R25.2
unnamed: C8.1, C9.1, JP1.1 (A), U3.5 (VOUT)
unnamed: JP3.2 (C), U7.4 (~RE), U7.5 (DE)
unnamed: F1.2, PS1.1 (+VIN_(VCC))
unnamed: PS1.6 (REMOTE_ON/OFF), Q1.3 (C)
unnamed: Q1.1 (B), R2.2, R3.2, R4.1
unnamed: Q2.1 (B), R19.2
unnamed: Q2.3 (C), R22.1
unnamed: R25.1, TP4.1 (1_1)
unnamed: TP3.1 (1_1), U1.1 (PGOOD)
unnamed: C7.1, U1.8 (VCC)
unnamed: C5.1, L1.2, U3.1 (VIN), U3.3 (EN)
unnamed: R12.1, U4.21 (RXD/SPI_MOSI)
unnamed: R14.1, U4.19 (SCL/SPI_CLK)
unnamed: R13.1, U4.18 (SDA/~SPI_CS)
unnamed: R11.1, U4.20 (TXD/SPI_MISO)
unnamed: R9.1, U4.5 (USB_DM)
unnamed: R10.1, U4.6 (USB_DP)
unnamed: R15.1, U4.9 (VCC_RF)
unnamed: R16.1, U5.6 (TxD)
unnamed: R17.1, U6.3 (RxD)

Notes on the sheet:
Propojeni s hrebinkem pomoci tohoto: https://mou.sr/4wiD7Ls nebo ekvivalentu.
TVS-uni
MOUNTING HOLES
USB propj: https://www.mironet.cz/aqua-computer-internal-usb-connection-cable-25-cm+dp673099/ https://www.google.com/aclk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…

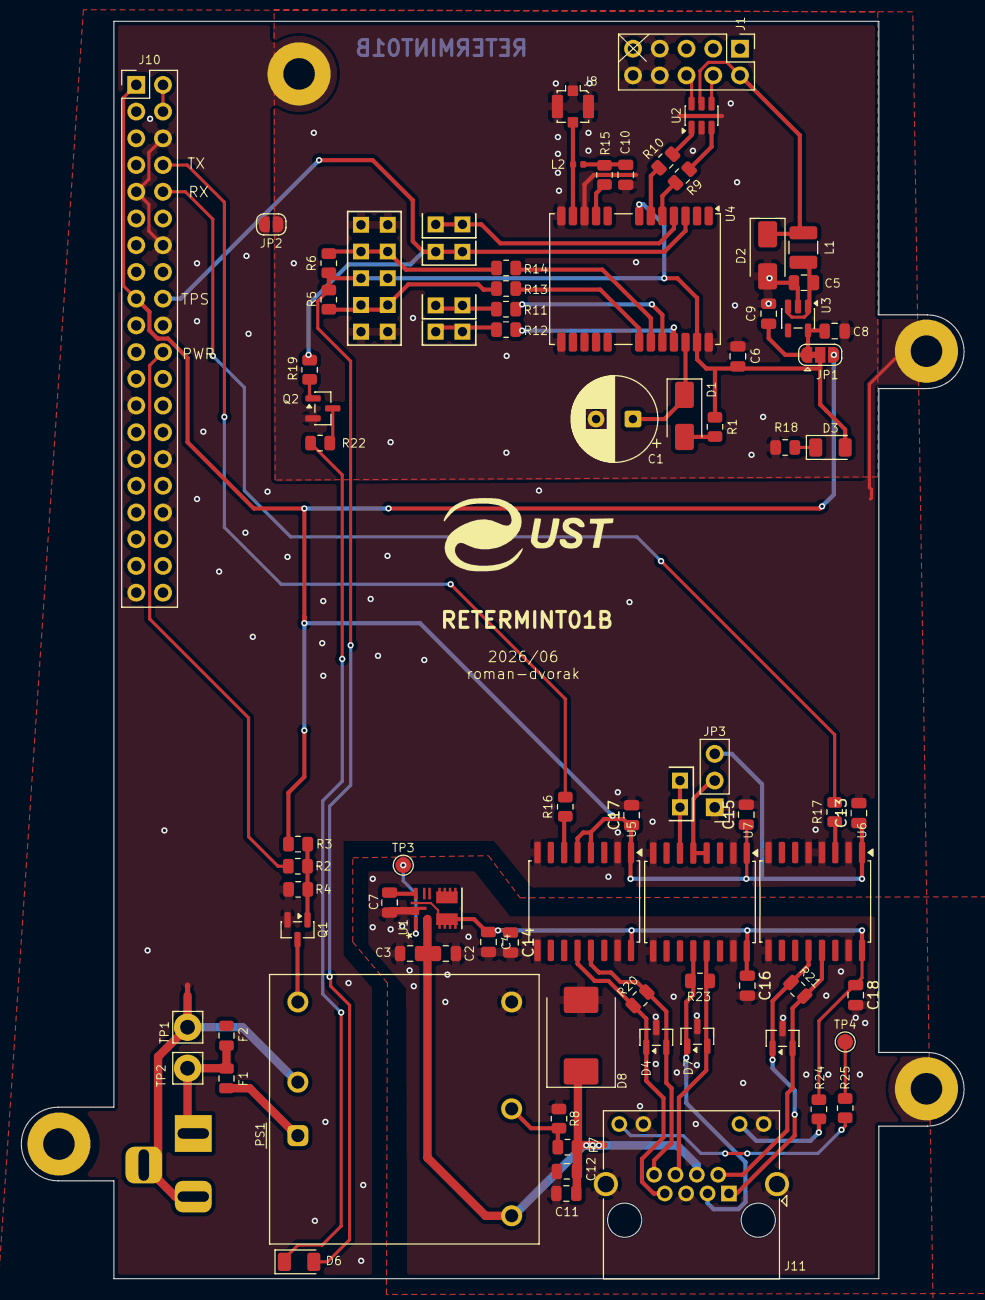
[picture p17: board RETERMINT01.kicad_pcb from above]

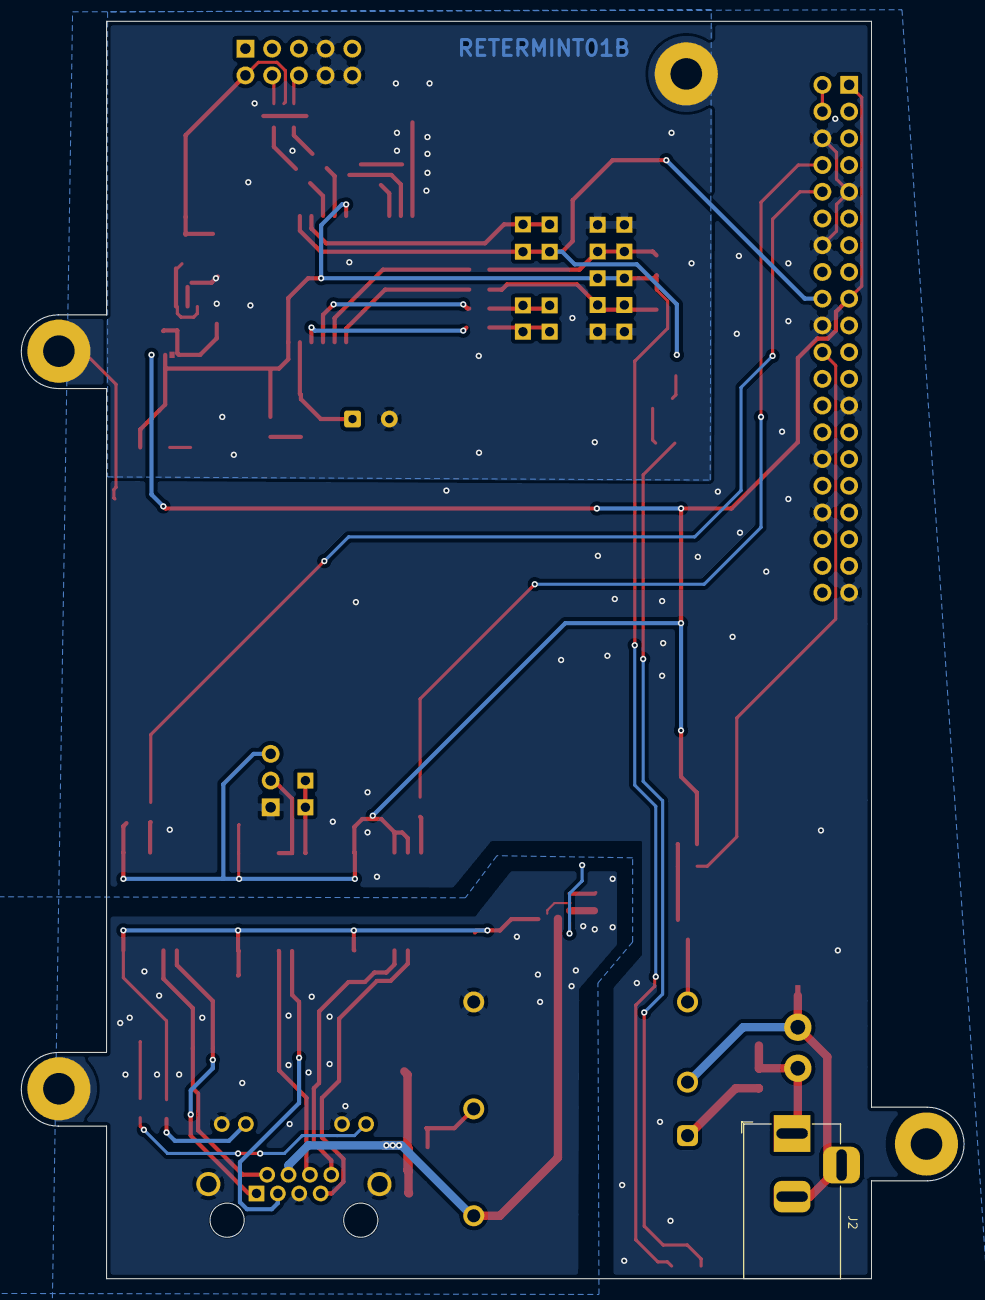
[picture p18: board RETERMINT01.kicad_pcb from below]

Board: 2 copper layers, 89.6 x 119.5 mm, 88 parts (2 on the bottom side), 60 nets.

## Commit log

2026-05-10 initial version of RETERMINAL DM interface module
    [RETERMINT01.kicad_pcb, RETERMINT01.kicad_sch]
2026-05-11 Automatic update of KiCAD outputs
    [RETERMINT01-B_Adhesive.dxf, RETERMINT01-B_Courtyard.dxf, RETERMINT01-B_Cu.dxf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]
2026-05-18 wip, layout
    [RETERMINT01.kicad_pcb, RETERMINT01.kicad_sch]
2026-05-18 PS1 default-off: add pull-up on Q1 base, rework R2/R3
    [RETERMINT01.kicad_pcb, RETERMINT01.kicad_sch]
2026-05-18 Fix D1 symbol type, fill title block
    [RETERMINT01.kicad_sch]
2026-05-18 Rework README: update intro, SVG schematic, remove block diagram and license
2026-05-18 Use div for PCB images instead of table
2026-05-18 update layout
    [RETERMINT01.kicad_pcb]
2026-05-18 ci: pin doc/assets to KiCADv9 branch + bump to current HEAD
    - .gitmodules: track KiCADv9 (matches the KiCad version actually
    used). Without this, `git submodule update --remote` in
    update_actions.yml would pull KiCADv10 (submodule default branch)
    and silently swap kibot/workflow files.
    - doc/assets: bump f49c1a5 -> 3c591db (latest KiCADv9, includes
    the v2_dk9 workflow template).
2026-05-18 update hader position
    [RETERMINT01.kicad_pcb]
2026-05-26 Update DC/DC label
    [RETERMINT01.kicad_pcb, RETERMINT01.kicad_sch]
2026-05-27 Update submodule to UST assets.
    [RETERMINT01.kicad_sch]
2026-05-27 Fix #2 Fix DRC errors. Improve layout.
    [RETERMINT01.kicad_pcb, RETERMINT01.kicad_sch]
2026-05-27 Update actions products
    [RETERMINT01-B_Adhesive.dxf, RETERMINT01-B_Courtyard.dxf, RETERMINT01-B_Cu.dxf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]
2026-05-31 Update component values.
    [RETERMINT01.kicad_pcb, RETERMINT01.kicad_sch]
2026-06-25 fix issues
    [RETERMINT01.kicad_pcb, RETERMINT01.kicad_sch]
